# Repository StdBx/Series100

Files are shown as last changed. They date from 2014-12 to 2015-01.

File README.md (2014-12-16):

Series100
=========

StdBx is a set of tools and libraries intended to make it easy to create professional looking control and display panels for your electronics DIY projects.  Series100 is a design point for an enclosure that looks like this:  

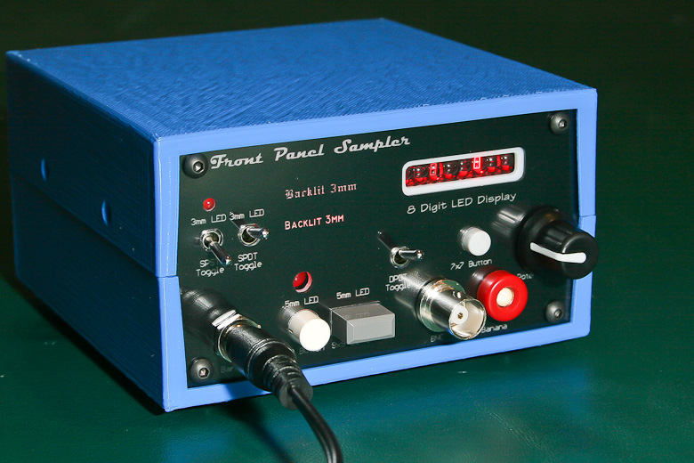
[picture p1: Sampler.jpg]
Series100 Sampler Enclosure shows a range of possible switches and displays
  
Series100 Sampler Enclosure 

The panels fit into an enclosure that has mounting for the circuit boards and end panels.  The enclosure design is provided in .stl format that can be printed on a 3d printer or ordered from a 3d print service company like [MakeXYZ](http://www.makexyz.com/) or [Shapeways](http://www.shapeways.com/).  

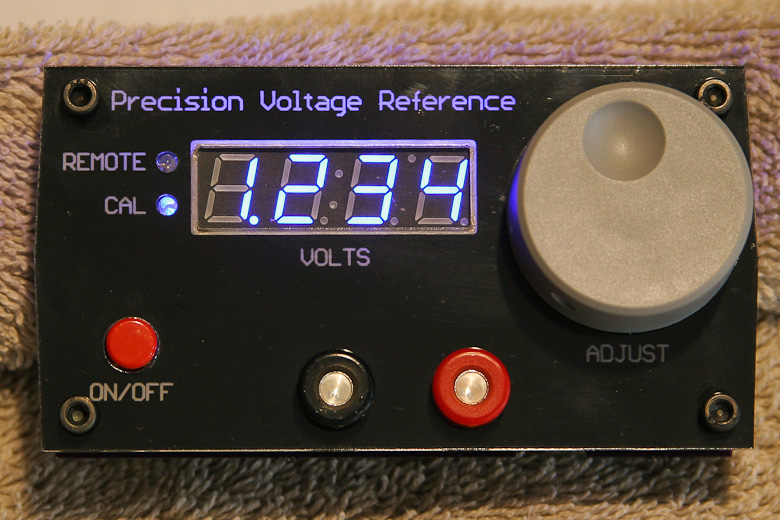
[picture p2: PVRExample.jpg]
Series100 Inside
  
Front Panel Example (early prototype)

Series100 adds a library and a CAM file to the EagleCAD PCB design software.  As you design your circuit board the front panel is designed along with it.  It is easy to use following these steps.  

  1. Design your circuit using Eagle's schematic capture tool.  For displays, buttons, switches, encoders, potentiometers and LEDs choose components from the Series100 library.  Include the Series100 board definition from the library.  
  2. Place the display and control components (along with the other components used in your design) using Eagle's PCB layout tool.  
  3. Add any text labels you would like to have on the panel.  
  4. Export the panel definition using the CAM file and scripts provided.  
  5. Order your panel from a laser cutting service like [Pololu](http://www.customlasercutting.com/) using the exported files.

That's it.  The board and the panel fits accurately and securely in the enclosure.  Together they allow your unique project to look like it just rolled off the manufacturing line.  

For a more detailed description and instructions start with the [!READ ME FIRST](https://github.com/StdBx/Series100/blob/master/Documentation/!READ%20ME%20FIRST.pdf) file in the Documentation folder.  You can also read more at the SparkFun forum [here](https://forum.sparkfun.com/viewtopic.php?f=5&t=39492).  

License: All design files are licensed under Creative Commons Universal.  You are welcome to modify the designs or even use them in commercial products.  We ask that you acknowledge that your design is based on StdBx and hope that if you create any additional components or enclosure designs that you contribute them back to the StdBx libraries.  

The StdBx name is copyright (c) 2014 C.Schnarel, all rights reserved. (i.e. don't create stuff and call it StdBx if it isn't part of one of the StdBx repositories.)

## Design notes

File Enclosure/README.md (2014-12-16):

Series100 Enclosure
===================

The StdBx Series100 is a box for your electronic projects.  The size is 4.25"W x 2.375"H x 4.1875"D.

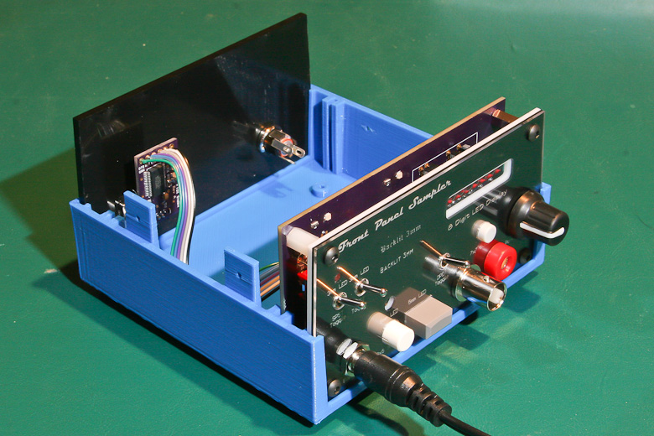
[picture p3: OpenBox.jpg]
Series100 Inside
  
Series100 Inside 

As you can see in this picture the StdBx system is based on a mechanical architecture similar to that used by any number of other instruments. There is an acrylic faceplate with a PCB behind it. The PCB is small enough to be designed with the free version of Eagle CAD, but can have a little over 8.5 square inches of circuitry. If that's not enough, the enclosure supports more PCBs on the back panel and floor of the enclosure for a total of 26.5 square inches of circuitry. You can add even more PCBs if you get creative by stacking. You don't have to use that much PCB but it's available if you need it.  

The floor of the enclosure is also sized to fit a 4xAA cell battery holder for more portable projects. You can use standard panel mount connectors on the back panel instead of a PCB. The two shown are a barrel jack for power and a rugged USB-mini-B connector with FTDI serial converter.

The enclosure is assembled from two identical pieces.  The two pieces are fastened with two screws on each side.  Together they capture the front and back panels and their associated PCBs.  There are mounting bosses for the third PCB on the floor of the enclosure.

The file Series100halfcaseRev3.1.stl in this folder is the mechanical definition for the enclosure.  You can print the file on your 3D printer or order it from 3D print companies like [MakeXYZ](http://www.makexyz.com/) or [Shapeways](http://www.shapeways.com/).  We have used both sources and the resulting prints work great.

The pieces we have tested from MakeXYZ were printed from PLA at a 200 micron layer height.  The pieces from Shapeways were printed from their "Strong & Flexible Plastic" material.  Both sources provide a range of print colors.

If you click on the stl file GitHub will provide an interactive 3D rendering.

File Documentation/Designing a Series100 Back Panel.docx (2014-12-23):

# Designing a Series100 Back Panel

The two ends of the Series100 enclosure are the same so strictly speaking you could put a “front” panel on both ends if you like, but often you don’t need the space or the cost of another circuit board. To fill this need for a simpler solution, the Series100 design point includes support for a back panel. Back panels are the same shape and size as front panels but they are made from a single piece of opaque acrylic and have no associated circuit board or PCB mounting holes.

Since the design is so simple you could just cut out a back panel piece by hand. You could drill it for connectors that have a round mounting hole, like a barrel jack. Then again, some connectors, like USB, have a more complex cutout shape, and the panel itself is a squashed hexagon, not rectangular. These additional complexities mean that, for me at least, getting a laser cut panel will result in a much better looking project than if I tried to fabricate the back panel by hand.

Use the steps below to create the back panel design files. Note that we’re still using Eagle even though we’re not designing a circuit board.

1. Using Eagle CAD create a new schematic file. Add the component “SERIES_100_BACKPANEL” (SB0029) from the “StdBxLibrary.lbr”. Place the component anywhere on your schematic.  NOTE: At this time the SERIES_100_BACKPANEL is in the “StdBxLibrary_BETA_.lbr” until it has been validated.
2. Click the “Generate/Switch to Board” button. You will get a dialog stating that your board file does not exist. Click “Yes” to create the board file from the schematic.
3. When the layout editor opens it will show the default board outline generated by Eagle. Delete the default board outline.
4. Click the “Layer Settings…” button and show layers 51, 244, and 246. Click “OK”.
5. Move the Series100 back panel so that the component origin is on the layout editor origin (the cross-hair). Once the board outline is moved you can click the “Zoom to Fit” button to make the board outline fill the edit window.
6. Click the “Switch to Schematic” button to go back to the schematic editor.
7. In the schematic editor add the rest of your back panel components. Components designed specifically for the back panel are noted in the component description. Most other components will not work since they mount to the PCB which is not there in this case.
8. Switch back to the board layout editor and place the components that you added. You don’t need to connect the components on the schematic or route them since there is no circuit board. Also, the components have an outline on the tDoc layer showing the size of the component. Don’t place components too close to the edges of the panel.
9. You can get a preview of your back panel layout by clicking on the “Layer Settings…” button and making layers 244 and 246 visible. Click “Apply”. This might give you a very cluttered view. To simplify the edit window and see the back panel more clearly, click the “None” button, then re-enable layers 244 and 246 and click “Apply”. Now you can see just the back panel items. When you are finished editing which layers to view, click the “Ok” button. Note that you cannot edit layers that are not visible.
10. Once you have your front panel laid out you can output the StdBx laser cutting and engraving files. NOTE: Just like outputting GERBER files, you do this only when your design is ready to be fabricated.  To output the StdBx files, click the “Run ULP” button in the layout editor. In the dialog that pops up choose “cam2dxf.ulp” and click “Open”. Next an open-file dialog will appear. In this dialog choose “StdBxSeries100.cam” and again click “Open”. Next another dialog will open with a Help tab. Click “OK” at this dialog. You will see some activity in the layout editor window, but pretty quickly that stops. If you then look in the same folder as the schematic and board layout you will see two new files, myBackPanelDesign_Bottom and myBackPanelDesign_Top. For the back panel you will only use the myBackPanelDesign_Top.
11. That’s it. You have designed your back panel.
12. See “Ordering the Back Panel” to get your back panel fabricated.

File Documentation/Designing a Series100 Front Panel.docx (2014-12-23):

# Designing a Series100 Front Panel

This is a first and pretty rough draft of the instructions for using Eagle to create a StdBx front panel layout. Provide feedback by opening issues in GitHub or send email to stdbxmdrtr@gmail.com.

1. Using Eagle CAD create a new schematic file. Add the component “SERIES_100” (SB0002) from the “StdBxLibrary.lbr”. Place the component anywhere on your schematic.
2. Click the “Generate/Switch to Board” button. You will get a dialog stating that your board file does not exist. Click “Yes” to create the board file from the schematic.
3. When the layout editor opens it will show two board outlines. The one on the left is the StdBx Series100 board definition. You can recognize it because it has mounting holes in the corners. The one on the right is the default board outline generated by Eagle. The default outline has no mounting holes. Delete the default board outline (the one on the right).
4. Move the Series100 board outline so that the bottom left corner is on the layout editor origin (the cross-hair). Once the board outline is moved you can click the “Zoom to Fit” button to make the board outline fill the edit window.
5. Click the “Switch to Schematic” button to go back to the schematic editor.
6. Draw the rest of your schematic. For LEDs, displays, switches, buttons, potentiometers, rotary encoders or any other component that “shows” through the front panel, choose only components from the “StdBxLibrary.lbr”. Components that do not show on the front panel can be chosen from any library. Note that even components that don’t show that are placed on the Top of the PCB can be no taller than 11 mm.
7. Continue your normal schematic edit and board layout process until your design is complete.
8. You can get a preview of your front panel layout by clicking on the “Layer Settings…” button and making layers 244, 245 and 246 visible. Click “Apply”. This might give you a very cluttered view. To simplify the edit window and see the front panel more clearly, click the “None” button, then re-enable layers 244, 245 and 246 and click “Apply”. Now you can see just the front panel items. When you are finished editing which layers to view, click the “Ok” button. Note that you cannot edit layers that are not visible.
9. If you wish to add labels or legends to your front panel you can do so by clicking the “Text” tool button. When the dialog opens type in your text and click “Ok”. Before you place your text, set the layer to “245 FP-Reveal” and the Ratio to “0%”. You can set the size to anything you like however smaller text does not engrave as well as larger text. I have found that .05” is about the smallest I’m comfortable with. Once you have set the layer, size and ratio you can place the text wherever you would like. Keep in mind that the enclosure covers the outermost 1/16” of the front panel and knobs cover more than just the diameter of the shaft.
10. Once you have your front panel laid out and text placed you can output the StdBx laser cutting and engraving files. NOTE: Just like outputting GERBER files, you do this only when your design is ready to be fabricated. If you output your StdBx files and then make more edits to the PCB then the front panel might not match the PCB anymore.  To output the StdBx files, click the “Run ULP” button in the layout editor. In the dialog that pops up choose “cam2dxf.ulp” and click “Open”. Next an open-file dialog will appear. In this dialog choose “StdBxSeries100.cam” and again click “Open”. Next another dialog will open with a Help tab. Click “OK” at this dialog. You will see some activity in the layout editor window, but pretty quickly that stops. If you then look in the same folder as the schematic and board layout you will see two new files, myDesign_Bottom and myDesign_Top.
11. That’s it. You have designed your front panel. If you find you do have to edit your PCB layout, just remember to go back and repeat step 10. Also, the text placed on layer 245 does NOT move automatically when you move components so remember to move the text when you move the component it goes with.
12. See “Ordering the Front Panel” to get your front panel fabricated.

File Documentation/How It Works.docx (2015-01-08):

# How it works

Although each project is different, all StdBx designs use a common architectural structure to fit into the enclosure. A cross section diagram of the structure shows how the parts work together.

The design starts with a PCB that has the user interface components (buttons, switches, displays, connectors, etc) mounted to it. In front of the PCB is the front panel that protects the PCB components and provides the surface for labels. There is a library of common components that the designer can choose from. Each component in the library was chosen so that it looks and works well with the structure. The PCB and the panel are separated by threaded spacers and are captured and held in place by channels in the enclosure.

The front panel is designed as a sandwich of three layers. I call these Epi, Reveal and Diffuser. The top Epi layer is always clear with cutouts for controls or connectors that protrude through the panel. The middle Reveal layer is opaque with cutouts for protrusions and labels. The bottom Diffuser layer is translucent. It has cutouts for protrusions and things like displays that should not be blurred.

Without backlight the Diffuser layer enhances the contrast of the cutouts in the Reveal layer. With backlight the labels or indicators cut in the Reveal layer light up. In terms of laser cut plastic there are actually just two pieces that are fastened together when mounted in the enclosure. The Reveal layer is bonded to clear acrylic (i.e. 2-ply acrylic). This is so that letter interiors don't fall away as part of the engraving process. When the Reveal layer is engraved away, it leaves the surface of the acrylic rough making it translucent rather than transparent so it can act as the Diffuser layer.

Here’s another cross section example.

<display section>

In this case a graphical display is mounted to the PCB. There is a cutout in the Reveal layer so that the backlit LCD shines through. There is also a cutout in the Diffuser layer so that the display is not blurred. Note that there is NOT a cutout in the clear Epi layer so the display is protected. Also, the Reveal and Diffuser layers are not exactly the same size making for a bezel around the display that dresses it up.

Here is another way to look at it. The lines in each of the Epi, Reveal and Diffuser layers define cutouts for that layer. Lines in Epi and Diffuser cut all the way through. Since Reveal and Diffuser are bonded together we cut through the Reveal layer using engraving. A side-effect or caveat is that since cutouts in the Diffuser layer cut all the way through, they are automatically cutouts in the Reveal layer. Watch out for this if you are designing your own components.

All the components in the StdBxLibrary have Epi, Reveal and Diffuser layers defined for the specifics of that component. The engraving and cutouts in these layers along with the PCB layout information and the mechanical characteristics have all been chosen so that they fit with the spacing between the PCB and the front panel as well as the thickness of the front panel.

When you place a component from the StdBxLibrary onto your PCB you are also placing that component’s Epi, Reveal and Diffuser definitions. Placing the “SERIES_100” (SB0002) component has the added function of defining both the PCB and the front panel outlines.

When you run the ULP with the StdBxCAM file, you cause Eagle CAD to output two files that the laser cutting service can translate into commands for the laser. One file is for the front panel Top piece. The other file is for the 2-ply front panel Bottom piece.

An alternative construction, that is more expensive but looks a little better, uses separate pieces of acrylic for the Reveal and Diffuser layers.

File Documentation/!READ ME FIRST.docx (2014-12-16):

# READ ME FIRST

This is a first and pretty rough draft. Provide feedback by opening issues in GitHub or send email to stdbxmdrtr@gmail.com.

The StdBx instruction files are all task based. That is, they are focused on the steps for getting one thing done. This keeps each set of instructions simpler and no more than a page or two in length.

This document describes things at more of an introductory or overview level. It provides a roadmap leading to the individual instruction files.

All of the instructions and StdBx files were created for and tested using Eagle CAD version 6.6.0 running on a Windows 7 computer. If your operating system or version of Eagle is different, you may have to adjust the instructions some. The instructions also assume that you are somewhat familiar with creating circuit boards using Eagle CAD. If you have little or no experience with Eagle, you might want to start by getting familiar with Eagle before adding StdBx. At a minimum you should already have Eagle installed and have learned to create schematic and board files. There are plenty of tutorials and YouTube videos that teach these Eagle basics.

The first thing to do with StdBx is to install it. The instructions for that are in the file “Installing StdBx Files into Eagle”.

Then to start your StdBx design, follow the instructions in the file “Designing a Series100 Front Panel”. If instead you are designing a back panel, follow the instructions in “Designing a Series100 Back Panel”.

To have your front panel laser cut from acrylic, follow the instructions in “Ordering the Front Panel”.

A key part of making StdBx work is getting the right components. For some help getting the parts for your circuit board, front panel, and the enclosure, follow the instructions in “Finding Parts for Your StdBx”.

That is really all you need for the basics. The following topics teach you how to do more customization. These tasks will make your front panel more unique, but with that you also take more risk that you might require more than one try to get things right. Plus you will have to use tools beyond Eagle CAD. Using these additional steps may also increase the cost of the front panel. Front panels are not too expensive, around $15. But if you have to try three times to get one that works that’s around $45 and that is expensive. Like anything, practice will help you make fewer mistakes, but if you are concerned with spending or with having your front panel not work right, stick with the steps above. I can’t guarantee that sticking to the steps above will always create a perfect front panel on the first try but that is what StdBx is designed for and we’ll continue to work to get as close to that as we can.

[Optional and Dangerous] To add a part that is not in the StdBx library, follow the instructions in “Creating a New Series100 Component”.

[Optional and Dangerous] Eagle supports only its own fonts (proportional and vector) from within the program; to learn how to create a front panel with other fonts, follow the instructions in “Using Custom Fonts on Your Front Panel”.

The instruction files above tell you how to use StdBx. In the “How It Works” document I will give a little information on how StdBx creates front panel files from your Eagle design. You don’t need to know how StdBx works to use the basics, but having a deeper understanding might help you move to the “Optional and Dangerous” topics, or might just give you more confidence in StdBx overall.

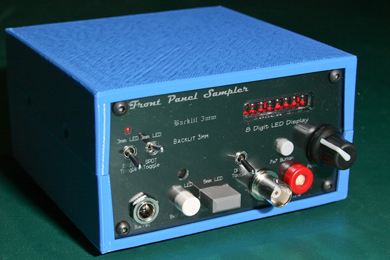
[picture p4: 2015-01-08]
SamplerHalfSize.jpg

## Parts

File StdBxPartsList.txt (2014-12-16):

Part No.,Name,Rev,Filetype,Description,Status
SB0001,"Enclosure, Series100halfcase",3.1,.stl,Enclosure component. Two pieces required (plus front and back panels) to form enclosure.,Beta
SB0002,"Panel, Series_100, Front with PCB",1.0,.lbr,"Eagle lbr component.  Defines front panel outline with mounting holes.  Defines standard PCB outline with mounting holes, keepouts and height restrictions.",Beta
SB0003,"Switch, Push Button, DPDT, 7mm Round Cap",1.0,.lbr,Push button for front panel with round cap.  Available in momentary and push-on/push-off.  Various cap colors.,Beta
SB0004,"Display, 7-Seg 4-Dig LED",1.0,.lbr,"LED 4-digit display, 10mm(0.39"") high, with bezel.  Available in various colors.",Beta
SB0005,"Display, 16x2 LCD ",1.0,.lbr,LCD display with bezel. Based on 16x2 LCD display from SparkFun library.  Parallel interface version.,Beta
SB0006,"Display, 7-Seg 8-Dig LED",1.0,.lbr,"LED 8-digit display with bezel.   Display height, 0.2"", appears larger due to bubble.  See SB0025 for module definition.",Beta
SB0007,"LED, 3mm, Clear",1.0,.lbr,Single 3 mm LED.  LED lens on front panel is clear. (cut out on reveal and diffused layers),Beta
SB0008,"LED, 3mm, Diffused",1.0,.lbr,Single 3 mm LED.  LED lens on front panel is diffused. (cut out on reveal layer only),Beta
SB0009,"LED, 5mm, Clear",1.0,.lbr,Single 5 mm LED.  LED lens on front panel is clear. (cut out on reveal and diffused layers),Beta
SB0010,"LED, 5mm, Diffused",1.0,.lbr,Single 5 mm LED.  LED lens on front panel is diffused. (cut out on reveal layer only),Beta
SB0011,"Switch, Encoder, Rotary",1.0,.lbr,Encoder with push-button.,Beta
SB0012,Potentiometer,1.0,.lbr,Potentiometer.  Various values.  Linear or log taper.,Beta
SB0013,"Switch, Toggle, SPST",1.0,.lbr,"Toggle switch, SPST (2 pin),  off/on.  Can be mounted with or without front nut.",Beta
SB0014,"Switch, Toggle, SPDT",1.0,.lbr,"Toggle switch, SPDT (3 pin).  Can be mounted with or without front nut.  Available in on-on, on-off-on, mom-off-mom, on-off-mom, on-mom.",Beta
SB0015,"Switch, Toggle, DPDT",1.0,.lbr,"Toggle switch, DPDT (6 pin).  Can be mounted with or without front nut.  Available in on-on, on-off-on.",Beta
SB0016,"Connector, BNC",1.0,.lbr,Mounts to front panel with nut (back side) AND soldered to circuit board.,Beta
SB0017,"Connector, Banana Plug Recepticle",1.0,.lbr,Accepts standard 5mm banana plug.  Available in various colors.  Mounts to front panel with nut (back side) AND soldered to circuit board.,Beta
SB0018,"Connector, Power, Barrel Jack 2.1x5.5",1.0,.lbr,Mounts to front panel with nut (front side) AND soldered to circuit board.,Beta
SB0019,"Switch, Push Button, DPDT, 6x12mm Rect Cap",1.0,.lbr,Push button for front panel with rectangular cap.  Available in momentary and push-on/push-off.  Various cap colors.,Beta
SB0020,"Switch, Push Button, DPDT, 6mm Round Cap",1.0,.lbr,Push button for front panel with round cap.  Available in momentary and push-on/push-off.  Various cap colors. Caps hard to find.,Beta
SB0021,"Connector, USB mini-B",1.0,.lbr,BACK PANEL ONLY - DOES NOT MOUNT TO PCB!  Defines cutouts for mounting connector to back panel but wrong height for std PCB mount.  See SB0023 or SB0024 for daughter-card to ribbon cable to PCB.,Beta
SB0022,"Connector, Power, BACK PANEL ONLY, Barrel Jack 2.1x5.5",1.0,.lbr,BACK PANEL ONLY - DOES NOT MOUNT TO PCB!  Defines cutouts for mounting connector to back panel but wrong height for std PCB mount.  Use wires to connect to PCB.,Beta
SB0023,"Module, USB",1.0,Eagle,Bridges connector pins to ribbon cable.  Use for applications that take USB directly.  See SB0024 for FTDI.,Beta
SB0024,"Module, FTDI, USB-to-serial",1.0,Eagle,Puts USB to serial onto USB connector then ribbon cable to main PCB.  Std 6-pin FTDI interface.,Beta
SB0025,"Module, Display, 7-Seg 8-Dig LED",1.0,Eagle,PCB design files for 8 digit LED display based on HP Bubble 4-digit parts.  Serial input for segments reduces pins.,Beta
SB0026,"PCB, Series100, Base",1.0,Eagle,PCB design files for board that mounts to bottom of enclosure.,Beta
SB0027,"PCB, Series100, Proto",1.0,Eagle,PCB design files for prototyping board that fits Series100 case and front panel.  Overlay components in Eagle to generate Front Panel files.,Beta
SB0028,"PCB, Series100, Proto with UNO",1.0,Eagle,PCB design files for prototyping board that fits Series100 case and front panel with mounting for Arduino UNO board.  Overlay components in Eagle to generate Front Panel files.,Beta
SB0029,"Panel, Series_100, Back",1.0,.lbr,"Eagle lbr component.  Defines panel outline without mounting holes.  No PCB definition.  For mounting ""panel mount"" components like SB0021 and SB0022.",Beta
SB0030,"Switch, Push Button, DPDT, 5x5mm Rect Cap",1.0,.lbr,Push button for front panel with rectangulare cap.  Available in momentary and push-on/push-off.  Various cap colors.,Beta
SB0031,"Switch, Encoder, Rotary",1.0,.lbr,Encoder with push-button.,Beta

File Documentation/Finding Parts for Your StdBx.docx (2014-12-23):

# Finding Parts for Your StdBx

The instructions here are focused on the task of choosing StdBx components and acquiring matching parts. For a more “Why?” and “How is it implemented?” description see the document “StdBx PartsBD”.

As you go about designing the user interface for your project you will probably think in terms of building blocks like buttons or different kinds of displays. You can find a selection of these types of components in the StdBxLibrary.lbr.

NOTE: START UP ISSUE: At this time most components are in the “StdBxLibrary_BETA_.lbr” until they have been validated.

Each component in the library has a description that tells the details about the component and what variations are available. The description also includes a StdBx part number. Hopefully there is enough information in the description to allow you to choose the component that you want, but eventually you will want to get more detail or more likely you will need to purchase parts for your project.

To research a part in more depth, or to purchase it, note the StdBx part number from the library. If you have Excel or can open Excel files in your spreadsheet program, open the “PartsDB.xlsx” file and switch to the “Vendor Parts” tab. If you do not have a spreadsheet, the same information is also available in the text file, “VendorPartNumsDB.txt”.

Once you have the file open, search for the StdBx part number that you noted earlier. You will find at least one and potentially many file entries with that part number. You will need to choose the one that best fits your needs. Once you have the entry you want, use the vendor and part number for that entry.

Let’s use an example to illustrate the process. You have decided to use a single-pole, double-throw toggle switch (SB0014) in your project. The switch is used to control an animated LED display and has three positions. In one position the LED animation is off. In another position the LED animation runs. In the third position the LED animation can be advanced one step at a time. The switch we are looking for is an on-off-mom version.

If you look in the parts database you will find that there are twelve entries with the SB0014 part number. Any of these parts will mechanically fit onto the PCB and will work properly with the front panel design. Reading through the descriptions you can see that only one of the entries has the desired on-off-mom function that we want. That switch is made by C&K and is their part number 107SHCQE. You can also see that this switch is stocked by Mouser (http://www.mouser.com/) part number 611-T105SHCQE and can be purchased in single units on their website.

There is a reasonable selection of components in the StdBxLibrary to design your front panel and more will be added over time. It might be valuable to read through the list of available components to have that knowledge as you plan out your design. If there is something that you need that is not available, you can follow the instructions in the file “Creating a New Series100 Component” to create it for yourself. Or if it is a component that you feel many would be interested in using you can open an enhancement issue on GitHub (https://github.com/StdBx/Series100). Or create it yourself and submit your component via a GitHub pull request.

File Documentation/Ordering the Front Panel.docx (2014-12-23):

# Ordering the Front Panel

This is a first and pretty rough draft. Provide feedback by opening issues in GitHub or send email to stdbxmdrtr@gmail.com. These instructions were developed on and for Eagle 6.6.0 running on a Windows 7 PC. If you have a different version of Eagle or a different OS you may need to adapt the instructions to your system.

Once you have finished your design in Eagle and have output the front panel files you are ready to order the laser cut acrylic pieces. The instructions here will walk you through ordering laser cut parts from Pololu (http://www.customlasercutting.com/); however other laser cutting and engraving services should be able to accomplish the same result. If you use another service you will have to adapt these instructions to the order process of the service you use.

Before you can place an order for your front panel parts you need to request a quote (http://www.customlasercutting.com/quote/overview). This is where you upload your design files, tell the service what material you want the parts cut from and explain any other special instructions needed. To make one front panel you are going to order two parts. From Pololu’s perspective you are ordering two laser cutting designs.

On the “New quote (http://www.pololu.com/laserquote/new)” page click on the “Browse…” button. In the dialog that opens navigate to your Eagle Projects folder and select the mydesign_Top file. Click Open to upload the file.

Paste the following text into the “Quantity:” window.

1 copy of layout defined in the file

Paste the following text into the “Special Instructions:” window.

StdBx Series100 Front Panel Design (top)
All lines in this file are cuts all the way through.
Material: 1/16" Transparent Clear Acrylic
Scale: mm, component should be 4.1" by 2.2"

Below the Special Instructions window will be a list of all the different materials available. Find the line that looks like the picture below and click the “Use this material” button at the right of the line.

When you click the “Use this material” button the Pololu page updates with a summary of your request. Check that the summary matches what you intend to order. Below the summary is the “Add another design” button. Click it.

Again the page will update. Click the “Browse…” next to My Files: and navigate to your Eagle Projects folder and select the mydesign_Bottom file. Click Open to upload the file.

Paste the following text into the “Quantity:” window.

1 copy of layout defined in the file

Paste the following text into the “Special Instructions:” text box.

StdBx Series100 Front Panel Design (bottom)
Material: IPI Laserables Reverse LZR901G 1/16"
2-ply, engraved on opaque side
Scale: inches, component should be 4.1" by 2.2"
Layer 244 (yellow): cut all the way through
layer 245 (magenta): Engraved reverse. Text should read correct when viewed from NOT engraved side. Text stroke width should be 0.015 inches. All closed shapes (layer 245 ONLY) should be filled.
Engrave Depth: .003" (opaque layer to be engraved off leaving engraved area translucent)

Scroll all the way to the bottom of the web page. There you will find another text box and button that looks like this:

Paste the following text into the box and click the “Use this material” button to the right of the box.

IPI Laserables Reverse LZR901G 1/16"

NOTE: START UP ISSUE: Currently Pololu does not stock or even special order this 2-ply material. You can order the material from Johnson Plastics (http://www.johnsonplastics.com/) and have them ship it to Pololu. Hopefully we will be able to get Pololu to stock this material soon.

Again the page will update. The new page will have a summary of both pieces for your design. If you are ordering a back panel at the same time, click the “Add another design” button. If not, check the box next to “I have read and understand the laser cutting capabilities and limitations…”. Then click the “I am a new customer” radio button and fill out the form to set up and account. Finally, click the “Submit quote request” button.

In a couple of days you should get a quote email that tells you how much your order will cost and provide a link to the quote. Click on the link. Once your quote page opens click on the links for the preview files. These are PDF files that Pololu has interpreted from the design files uploaded. Check these PDFs over carefully. The blue lines are cuts all the way through the material. The black lines and areas are the places that will be engraved. Once you approve the quote Pololu will make the pieces just like the files. If it’s wrong on the file and you approve it, Pololu will not be responsible.

After you have approved the check files scroll to the bottom of the page and click to place your order. The price goes up the faster you want your parts.

That’s it. Your front panel will be shipped to you on the schedule you requested. Of course, you also need to order the parts that will go into your project. For some help ordering the StdBx parts, take a look at the instructions in the file “Finding Parts for Your StdBx”.

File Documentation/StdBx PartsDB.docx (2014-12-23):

# StdBx PartsDB

Just like the same mechanical package can be used for many different ICs, so too can the same Eagle library component be used for many different vendor parts. For example, the same library component can represent a red LED or a green one. What’s important to the library component is that the LEDs share the same mechanical shape, pad layout and panel cutouts or engravings. Similarly the same library component for a push button can represent a momentary contact button or a push-on/push-off button. The mapping from library component to vendor parts can be one to many.

The reverse is also true. The same vendor part for an LED can be used for the library component with panel cutouts to make it show through clear or with another library component that is an engraved spot to have the LED be diffused. Another example would be two different library components that represent the same switch, one with a round cap, the other with a rectangular cap. So the mapping from vendor part to library components can also be one to many.

To facilitate this many-to-many mapping StdBx uses a parts database rather than just the Eagle component library. Each library component carries the definition of the front panel layers as well as the normal schematic and board layout representations. Also, it is a requirement that the StdBx library components be readily available. Therefore there may be multiple vendors and/or multiple manufacturers for each component. Since both retailers and manufacturers add and drop components all the time, the information needs to be maintained dynamically but it would cause unnecessary churn to the Eagle library to have to update it every time a new vendor is found or a manufacturer introduces a new color.

The database need not be complex or require special tools. The master information will be maintained as a Microsoft Excel (.xlsx) file, but the data will also be saved as CSV text so that it can be imported into any spreadsheet or database, or just read as text.

Therefore: Each component in the StdBxLibrary.lbr will be assigned a part number. The format for the number is “SBxxxx” where xxxx is a four digit number. So that we can also track enclosure variants or other StdBx pieces, these too will receive a part number. A master list of StdBx part numbers will be maintained. Each entry will record the part number, name, revision, definition file type, description, and status. A second list will be maintained that contains a list of vendor parts that can be used with each StdBx library component. Each entry will record the vendor, vendor part number, StdBx part number, manufacturer, manufacturer part number, name and notes. No component shall be added to the library unless the part for that component is readily available.

The purpose of the master list of StdBx part numbers is to facilitate allocation of new part numbers and manage development and status of all StdBx components.

To find a part for your project determine the kind of part you need and choose that component from the component library. Note the StdBx part number. Then look up that StdBx part number in the vendor part number list. You may find multiple vendors or vendor part numbers that match. You should always find at least one.

If you should ever want to submit a new library component for inclusion in StdBx, please also submit one or preferably multiple vendors’ part numbers that fit the component.

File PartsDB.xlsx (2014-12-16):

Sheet: StdBx Parts
Part No. | Name | Rev | Filetype | Description | Status
SB0001 | Enclosure, Series100halfcase | 3.1 | .stl | Enclosure component. Two pieces required (plus front and back panels) to form enclosure. | Beta
SB0002 | Panel, Series_100, Front with PCB | 1.0 | .lbr | Eagle lbr component. Defines front panel outline with mounting holes. Defines standard PCB outline with mounting holes, keepouts and height restrictions. | Beta
SB0003 | Switch, Push Button, DPDT, 7mm Round Cap | 1.0 | .lbr | Push button for front panel with round cap. Available in momentary and push-on/push-off. Various cap colors. | Beta
SB0004 | Display, 7-Seg 4-Dig LED | 1.0 | .lbr | LED 4-digit display, 10mm(0.39") high, with bezel. Available in various colors. | Beta
SB0005 | Display, 16x2 LCD | 1.0 | .lbr | LCD display with bezel. Based on 16x2 LCD display from SparkFun library. Parallel interface version. | Beta
SB0006 | Display, 7-Seg 8-Dig LED | 1.0 | .lbr | LED 8-digit display with bezel. Display height, 0.2", appears larger due to bubble. See SB0025 for module definition. | Beta
SB0007 | LED, 3mm, Clear | 1.0 | .lbr | Single 3 mm LED. LED lens on front panel is clear. (cut out on reveal and diffused layers) | Beta
SB0008 | LED, 3mm, Diffused | 1.0 | .lbr | Single 3 mm LED. LED lens on front panel is diffused. (cut out on reveal layer only) | Beta
SB0009 | LED, 5mm, Clear | 1.0 | .lbr | Single 5 mm LED. LED lens on front panel is clear. (cut out on reveal and diffused layers) | Beta
SB0010 | LED, 5mm, Diffused | 1.0 | .lbr | Single 5 mm LED. LED lens on front panel is diffused. (cut out on reveal layer only) | Beta
SB0011 | Switch, Encoder, Rotary | 1.0 | .lbr | Encoder with push-button. | Beta
SB0012 | Potentiometer | 1.0 | .lbr | Potentiometer. Various values. Linear or log taper. | Beta
SB0013 | Switch, Toggle, SPST | 1.0 | .lbr | Toggle switch, SPST (2 pin), off/on. Can be mounted with or without front nut. | Beta
SB0014 | Switch, Toggle, SPDT | 1.0 | .lbr | Toggle switch, SPDT (3 pin). Can be mounted with or without front nut. Available in on-on, on-off-on, mom-off-mom, on-off-mom, on-mom. | Beta
SB0015 | Switch, Toggle, DPDT | 1.0 | .lbr | Toggle switch, DPDT (6 pin). Can be mounted with or without front nut. Available in on-on, on-off-on. | Beta
SB0016 | Connector, BNC | 1.0 | .lbr | Mounts to front panel with nut (back side) AND soldered to circuit board. | Beta
SB0017 | Connector, Banana Plug Recepticle | 1.0 | .lbr | Accepts standard 5mm banana plug. Available in various colors. Mounts to front panel with nut (back side) AND soldered to circuit board. | Beta
SB0018 | Connector, Power, Barrel Jack 2.1x5.5 | 1.0 | .lbr | Mounts to front panel with nut (front side) AND soldered to circuit board. | Beta
SB0019 | Switch, Push Button, DPDT, 6x12mm Rect Cap | 1.0 | .lbr | Push button for front panel with rectangular cap. Available in momentary and push-on/push-off. Various cap colors. | Beta
SB0020 | Switch, Push Button, DPDT, 6mm Round Cap | 1.0 | .lbr | Push button for front panel with round cap. Available in momentary and push-on/push-off. Various cap colors. Caps hard to find. | Beta
SB0021 | Connector, USB mini-B | 1.0 | .lbr | BACK PANEL ONLY - DOES NOT MOUNT TO PCB! Defines cutouts for mounting connector to back panel but wrong height for std PCB mount. See SB0023 or SB0024 for daughter-card to ribbon cable to PCB. | Beta
SB0022 | Connector, Power, BACK PANEL ONLY, Barrel Jack 2.1x5.5 | 1.0 | .lbr | BACK PANEL ONLY - DOES NOT MOUNT TO PCB! Defines cutouts for mounting connector to back panel but wrong height for std PCB mount. Use wires to connect to PCB. | Beta
SB0023 | Module, USB | 1.0 | Eagle | Bridges connector pins to ribbon cable. Use for applications that take USB directly. See SB0024 for FTDI. | Beta
SB0024 | Module, FTDI, USB-to-serial | 1.0 | Eagle | Puts USB to serial onto USB connector then ribbon cable to main PCB. Std 6-pin FTDI interface. | Beta
SB0025 | Module, Display, 7-Seg 8-Dig LED | 1.0 | Eagle | PCB design files for 8 digit LED display based on HP Bubble 4-digit parts. Serial input for segments reduces pins. | Beta
SB0026 | PCB, Series100, Base | 1.0 | Eagle | PCB design files for board that mounts to bottom of enclosure. | Beta
SB0027 | PCB, Series100, Proto | 1.0 | Eagle | PCB design files for prototyping board that fits Series100 case and front panel. Overlay components in Eagle to generate Front Panel files. | Beta
SB0028 | PCB, Series100, Proto with UNO | 1.0 | Eagle | PCB design files for prototyping board that fits Series100 case and front panel with mounting for Arduino UNO board. Overlay components in Eagle to generate Front Panel files. | Beta
SB0029 | Panel, Series_100, Back | 1.0 | .lbr | Eagle lbr component. Defines panel outline without mounting holes. No PCB definition. For mounting "panel mount" components like SB0021 and SB0022. | Beta
SB0030 | Switch, Push Button, DPDT, 5x5mm Rect Cap | 1.0 | .lbr | Push button for front panel with rectangulare cap. Available in momentary and push-on/push-off. Various cap colors. | Beta
SB0031 | Switch, Encoder, Rotary | 1.0 | .lbr | Encoder with push-button. | Beta

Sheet: Vendor Parts
Vendor # | Vendor | StdBx # | Status | Manufacturer | Mfr # | Name | Notes
611-PVB6THTOA300NS | Mouser | SB0003 |  | C&K | PVA6THT OA 300NS LFS | Switch, Push Button, DPDT, 7.4mm Round Cap, Momentary
611-PVB6THTEE300NS | Mouser | SB0003 |  | C&K | PVA6THT EE 300NS LFS | Switch, Push Button, DPDT, 7.4mm Round Cap, Push-on / Push-Off
401-1149-ND | Digi-Key | SB0003 |  | C&K | PV GY | Cap, Round 7.4 mm, Gray
401-1150-ND | Digi-Key | SB0003 |  | C&K | PV RD | Cap, Round 7.4 mm, Red
401-1148-ND | Digi-Key | SB0003 |  | C&K | PV BK | Cap, Round 7.4 mm, Black
401-1151-ND | Digi-Key | SB0003 |  | C&K | PV WH | Cap, Round 7.4 mm, White
COM-09483 | SparkFun | SB0004 |  | Young Sun | YSD-439AR6B-35 | Red, 7-Segment 4-Digit, 10mm (0.39") high, common anode, with colon & apostraphy
COM-10931 | SparkFun | SB0004 |  | ??? | ATA3492BW_2 | White, 7-Segment 4-Digit, 10mm (0.39") high, common anode, with colon & apostraphy
COM-09480 | SparkFun | SB0004 |  | Young Sun | YSD-439AY2B-35 | Yellow, 7-Segment 4-Digit, 10mm (0.39") high, common anode, with colon & apostraphy
COM-09482 | SparkFun | SB0004 |  | Young Sun | YSD-439AK2B-35 | Kelly Green, 7-Segment 4-Digit, 10mm (0.39") high, common anode, with colon & apostraphy
COM-09485 | SparkFun | SB0004 |  | Young Sun | YSD-439AB4B-35 | Blue, 7-Segment 4-Digit, 10mm (0.39") high, common anode, with colon & apostraphy
LCD-00709 | SparkFun | SB0005 |  | Xiamen Ocular | GDM1602K 5V | White on Black, 16x2 parallel input LCD
LCD-09052 | SparkFun | SB0005 |  | Xiamen Amotec Display Co Ltd | ADM1602K-NSW-FBS/3.3V | White on Black, 16x2 parallel input LCD
LCD-00255 | SparkFun | SB0005 |  | Xiamen Ocular | GDM1602K 5V | Black on Green, 16x2 parallel input LCD
LCD-09053 | SparkFun | SB0005 |  | Xiamen Amotec Display Co Ltd | ADM1602K-FSY-YBS/3.3V | Black on Green, 16x2 parallel input LCD
LCD-00790 | SparkFun | SB0005 |  | Xiamen Ocular | GDM1602K 5V | Yellow on Blue, 16x2 parallel input LCD
754-1604-ND | Digi-Key | SB0007 |  | Kingbright | WP710A10SRC/E | Red LED, 3mm, just one example of hundreds of compatible parts
754-1596-ND | Digi-Key | SB0007 |  | Kingbright | WP710A10QBC/D | Blue LED, 3mm, just one example of hundreds of compatible parts
754-1604-ND | Digi-Key | SB0008 |  | Kingbright | WP710A10SRC/E | Red LED, 3mm, just one example of hundreds of compatible parts
754-1596-ND | Digi-Key | SB0008 |  | Kingbright | WP710A10QBC/D | Blue LED, 3mm, just one example of hundreds of compatible parts
754-1274-ND | Digi-Key | SB0009 |  | Kingbright | WP7113SRC/DU | Red LED, 5mm, just one example of hundreds of compatible parts
754-1489-ND | Digi-Key | SB0009 |  | Kingbright | WP7113QBC/D | Blue LED, 5mm, just one example of hundreds of compatible parts
754-1274-ND | Digi-Key | SB0010 |  | Kingbright | WP7113SRC/DU | Red LED, 5mm, just one example of hundreds of compatible parts
754-1489-ND | Digi-Key | SB0010 |  | Kingbright | WP7113QBC/D | Blue LED, 5mm, just one example of hundreds of compatible parts
PEC12R-4225F-S0024-ND | Digi-Key | SB0011 |  | Bourns, Inc. | PEC12R-4225F-S0024 | ROTARY ENCODER, 24 counts per revolution, with switch, 6mm D-shaft | Needs shaft defn and knob ref
652-PEC12R-4225F-S24 | Mouser | SB0011 |  | Bourns, Inc. | PEC12R-4225F-S0024 | ROTARY ENCODER, 24 counts per revolution, with switch, 6mm D-shaft | Needs shaft defn and knob ref
987-1187-ND | Digi-Key | SB0011 |  | TT Electronics | EN11-HSB1AQ20 | ROTARY ENCODER, 20 counts per revolution, with switch, 6mm D-shaft | Needs shaft defn and knob ref
858-EN11-HSB1AQ20 | Mouser | SB0011 |  | TT Electronics | EN11-HSB1AQ20 | ROTARY ENCODER, 20 counts per revolution, with switch, 6mm D-shaft | Needs shaft defn and knob ref
PTV09A-4025F-Bxxx-ND | Digi-Key | SB0012 |  | Bourns, Inc. | PTV09A-4025F | Potentiometer, Rear Mount Bushingless, flat shaft | xxx = value. e.g. 103 = 10k, 202 = 2k, etc.
652-PTV09A-4025FBxxx | Mouser | SB0012 |  | Bourns, Inc. | PTV09A-4025F | Potentiometer, Rear Mount Bushingless, flat shaft | xxx = value. e.g. 103 = 10k, 202 = 2k, etc.
CKN10151-ND | Digi-Key | SB0013 |  | C&K | T102SHCQE | SWITCH, TOGGLE, SPST, 120V, 3A, PCB pins, off-on
611-T102SHCQE | Mouser | SB0013 |  | C&K | T102SHCQE | SWITCH, TOGGLE, SPST, 120V, 3A, PCB pins, off-on
612-200MSP6T1B1M2RE | Mouser | SB0013 |  | E-switch | 200MSP6T1B1M2RE | SWITCH, TOGGLE, SPST, 120V, 3A, PCB pins, off-on
CKN1091-ND | Digi-Key | SB0014 |  | C&K | T101SHCQE | SWITCH, TOGGLE, SPDT, 120V, 2A, PCB pins, on-on
611-T101-001 | Mouser | SB0014 |  | C&K | T101SHCQE | SWITCH, TOGGLE, SPDT, 120V, 2A, PCB pins, on-on
EG2447-ND | Digi-Key | SB0014 |  | E-switch | 200MSP1T1B1M2QEH | SWITCH, TOGGLE, SPDT, 120V, 2A, PCB pins, on-on
612-200-A1121 | Mouser | SB0014 |  | E-switch | 200MSP1T1B1M2QEH | SWITCH, TOGGLE, SPDT, 120V, 2A, PCB pins, on-on
CKN1092-ND | Digi-Key | SB0014 |  | C&K | T103SHCQE | SWITCH, TOGGLE, SPDT, 120V, 2A, PCB pins, on-off-on
611-T103-001 | Mouser | SB0014 |  | C&K | T103SHCQE | SWITCH, TOGGLE, SPDT, 120V, 2A, PCB pins, on-off-on
EG2451-ND | Digi-Key | SB0014 |  | E-switch | 200MSP3T1B1M2QEH | SWITCH, TOGGLE, SPDT, 120V, 2A, PCB pins, on-off-on
612-200-C1121 | Mouser | SB0014 |  | E-switch | 200MSP3T1B1M2QEH | SWITCH, TOGGLE, SPDT, 120V, 2A, PCB pins, on-off-on
611-T105SHCQE | Mouser | SB0014 |  | C&K | T105SHCQE | SWITCH, TOGGLE, SPDT, 120V, 2A, PCB pins, mom-off-mom
612-200MSP4T1B1M2QE | Mouser | SB0014 |  | E-switch | 200MSP4T1B1M2QEH | SWITCH, TOGGLE, SPDT, 120V, 2A, PCB pins, mom-off-mom
611-T105SHCQE | Mouser | SB0014 |  | C&K | 107SHCQE | SWITCH, TOGGLE, SPDT, 120V, 2A, PCB pins, on-off-mom
200MSP2T1B1M2RE-ND | Digi-Key | SB0014 |  | E-switch | 200MSP2T1B1M2RE | SWITCH, TOGGLE, SPDT, 120V, 2A, PCB pins, on-mom
612-200MSP2T1B1M2QE | Mouser | SB0014 |  | E-switch | 200MSP2T1B1M2RE | SWITCH, TOGGLE, SPDT, 120V, 2A, PCB pins, on-mom
CKN1182-ND | Digi-Key | SB0015 |  | C&K | T201SHCQE | SWITCH, TOGGLE, DPDT, 120V, 3A, PCB pins, on-on
T203SHCQE-ND | Digi-Key | SB0015 |  | C&K | T203SHCQE | SWITCH, TOGGLE, DPDT, 120V, 3A, PCB pins, on-off-on
611-T201-001 | Mouser | SB0015 |  | C&K | T201SHCQE | SWITCH, TOGGLE, DPDT, 120V, 3A, PCB pins, on-on
EG2456-ND | Digi-Key | SB0015 |  | E-switch | 200MDP1T1B1M2QE | SWITCH, TOGGLE, DPDT, 120V, 3A, PCB pins, on-on
612-200MDP3T1B1M2QE | Mouser | SB0015 |  | E-switch | 200MDP3T1B1M2QE | SWITCH, TOGGLE, DPDT, 120V, 3A, PCB pins, on-off-on
611-T201-001 | Mouser | SB0015 |  | E-switch | 200MDP1T1B1M2QE | SWITCH, TOGGLE, DPDT, 120V, 3A, PCB pins, on-on
A97548-ND | Digi-Key | SB0016 |  | TE Connectivity | 5-1634523-1 | BNC Connector, 50 Ohm, panel mount
J10124-ND | Digi-Key | SB0017 |  | Emerson Network Power Connectivity Solutions | 108-2302-621 | Banana Plug Recepticle, Red
J10142-ND | Digi-Key | SB0017 |  | Emerson Network Power Connectivity Solutions | 108-2303-621 | Banana Plug Recepticle, Black
CP-064A-ND | Digi-Key | SB0018 |  | CUI Inc | PJ-064A | Barrel Jack, 2.1x5.5mm
 | Digi-Key | SB0019 |  | C&K | PVA6THT OA 300NS LFS | Switch, Push Button, DPDT, 6x12mm Rect Cap, Momentary
 | Digi-Key | SB0019 |  | C&K | PVA6THT EE 300NS LFS | Switch, Push Button, DPDT, 6x12mm Rect Cap, Push-on / Push-Off
611-PVB6THTOA300NS | Mouser | SB0019 |  | C&K | PVA6THT OA 300NS LFS | Switch, Push Button, DPDT, 6x12mm Rect Cap, Momentary
611-PVB6THTEE300NS | Mouser | SB0019 |  | C&K | PVA6THT EE 300NS LFS | Switch, Push Button, DPDT, 6x12mm Rect Cap, Push-on / Push-Off
401-1153-ND | Digi-Key | SB0019 |  | C&K | PE GY | Cap, Rectangular 12x6 mm, Gray
401-1154-ND | Digi-Key | SB0019 |  | C&K | PE RD | Cap, Rectangular 12x6 mm, Red
401-1152-ND | Digi-Key | SB0019 |  | C&K | PE BK | Cap, Rectangular 12x6 mm, Black
401-1155-ND | Digi-Key | SB0019 |  | C&K | PE WH | Cap, Rectangular 12x6 mm, White
612-TL2230-OA | Mouser | SB0020 |  | E-Switch | TL2230OAF140 | Switch, Push Button, DPDT, 6mm Round Cap, Momentary
612-TL2230EEF100 | Mouser | SB0020 |  | E-Switch | TL2230EEF100 | Switch, Push Button, DPDT, 6mm Round Cap, Push-on / Push-Off
612-TL2230-OA | Mouser | SB0030 |  | E-Switch | TL2230OAF140 | Switch, Push Button, DPDT, 5x5mm Rect Cap, Momentary
612-TL2230EEF100 | Mouser | SB0030 |  | E-Switch | TL2230EEF100 | Switch, Push Button, DPDT, 5x5 Rect Cap, Push-on / Push-Off
612-1DFBLK | Mouser | SB0030 |  | E-Switch | 1DFBLK | Cap, Rectangular 5x5 mm, Black
612-1D-BLK | Mouser | SB0030 |  | E-Switch | 1D-BLK | Cap, Rectangular 5x5 mm, Black
612-1D-GR | Mouser | SB0030 |  | E-Switch | 1D-GRY | Cap, Rectangular 5x5 mm, Gray
450-BA600 | Mouser | SB0011 |  | Eagle Knobs & Dials | 450-BA600 | Knob, 16mm dia, 6mm D-shaft, Black body, no indicator
450-BA761 | Mouser | SB0012 |  | Eagle Knobs & Dials | 450-BA761 | Knob, 16mm dia, 6mm D-shaft, Black body, White indicator
450-BA261 | Mouser | SB0012 |  | Eagle Knobs & Dials | 450-BA261 | Knob, 16mm dia, 6mm D-shaft, Black body, Yellow indicator
450-BA161 | Mouser | SB0012 |  | Eagle Knobs & Dials | 450-BA161 | Knob, 16mm dia, 6mm D-shaft, Black body, Red indicator
450-BA361 | Mouser | SB0012 |  | Eagle Knobs & Dials | 450-BA361 | Knob, 16mm dia, 6mm D-shaft, Black body, Blue indicator
450-4760 | Mouser | SB0012 |  | Eagle Knobs & Dials | 450-4760 | Knob, 13.5mm dia, 6mm D-shaft, Black body, White indicator
450-4764 | Mouser | SB0012 |  | Eagle Knobs & Dials | 450-4764 | Knob, 13.5mm dia, 6mm D-shaft, Black body, Green indicator
450-4660 | Mouser | SB0012 |  | Eagle Knobs & Dials | 450-4660 | Knob, 13.5mm dia, 6mm D-shaft, Gray body, Black indicator
450-AE141 | Mouser | SB0031 |  | Eagle Knobs & Dials | 450-AE141 | Knob, 13.7mm dia, 6mm T18-shaft, Black body, White indicator
450-AE185 | Mouser | SB0031 |  | Eagle Knobs & Dials | 450-AE185 | Knob, 18.2mm dia, 6mm T18-shaft, Gray body, Black indicator
450-BA760 | Mouser | SB0031 |  | Eagle Knobs & Dials | 450-BA760 | Knob, 16mm dia, 6mm T18-shaft, Black body, White indicator

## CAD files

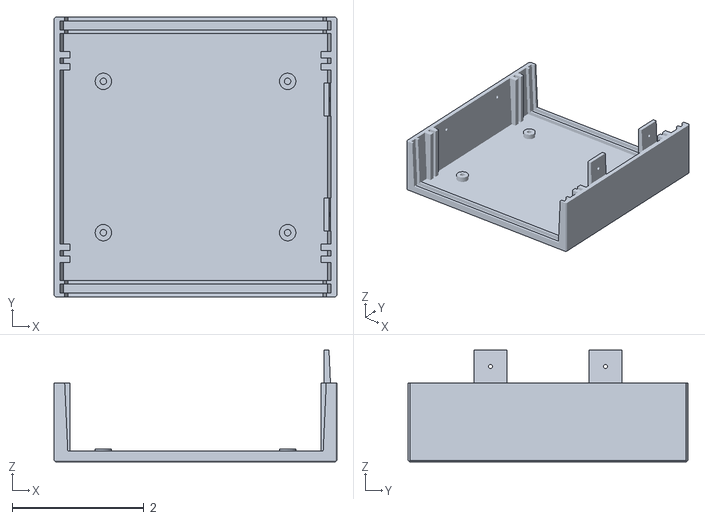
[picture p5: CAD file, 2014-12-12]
Enclosure/Series100halfcaseRev3.1.stl
4.30 x 4.25 x 1.70

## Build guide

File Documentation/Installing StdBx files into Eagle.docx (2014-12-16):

# Installing StdBx Files into Eagle CAD

This is a first and pretty rough draft. Provide feedback by opening issues in GitHub or send email to stdbxmdrtr@gmail.com. These instructions were developed on and for Eagle 6.6.0 running on a Windows 7 PC. If you have a different version of Eagle or a different OS you may need to adapt the instructions to your system.

If you are an experienced Eagle user and experienced with GitHub then here is the short version: Put the repository files from the Eagle Files folder in the right places. The .lbr files go in your Eagle Libraries folder. The .cam file goes in the Eagle cam folder. Optionally, you can also copy the Series100 Examples folder and its contents to your Eagle projects folder.

If the last paragraph is not so clear, read on.

In the Series100 repository (https://github.com/StdBx/Series100) there are two folders of files that need to be added to your Eagle CAD installation. The first step is to download the files from GitHub. And the easiest way to do that is to download the repository as a zip file by clicking on the Download ZIP button on the right-hand side of the repository screen.

The files go into different locations depending on how you set up Eagle on your system. The files can be stored in the Eagle installation folder, but that has some issues. First you have to be an administrator on your system and second the files will have to be moved or copied every time you get an update to Eagle.

A better solution is to create an Eagle folder in a separate place, like MyDocuments, and point Eagle at that. Here (http://www.baldengineer.com/blog/2014/01/03/eagle-create-custom-library/) is a good tutorial on setting up the folders outside of Eagle. You at least need to set up the library folder, the projects folder and the cam folder.

Once you have the folders set up, copy the file StdBxLibrary from the Eagle Files folder inside the zip file to the library folder you created. Copy the file StdBxSeries100 to the cam folder you created. Copy the Series100 Examples folder to the projects folder you created.

NOTE: There are two library files, StdBxLibrary and StdBxLibrary_BETA_. The BETA file contains additional components that have not yet been proven. You can install both if you want. If you use components from StdBxLibrary_BETA_, recognize that you have a greater risk of something not working right. And right now since StdBx is just getting started, virtually all the components are in the BETA library. These will move one-by-one to StdBxLibrary as they are proven.

The next time you open Eagle, the files you copied should show up in the Eagle Control panel in their respective folders. In the Libraries folder there is a dot to the right of the StdBxLibrary file. The dot is likely small and grayish. Click on the dot. It should become larger and green. This is telling Eagle to make this library active in the schematic editor.

Your StdBx additions to Eagle are now installed. You can start your StdBx design by following the instructions in “Designing a Series100 Front Panel”.

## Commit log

2014-12-12 Starting Documentation and initial files
    [PartsDB.xlsx, Series100halfcaseRev3.1.stl]
2014-12-12 Adding Libraries and Proto Boards
    [StdBx Proto Board w UNO(ALPHA).brd, StdBx Proto Board w UNO(ALPHA).sch, StdBx Proto Board(ALPHA).brd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]
2014-12-12 Adding documentation
    [StdBx Proto Board w UNO(ALPHA).brd, StdBx Proto Board w UNO(ALPHA).sch, StdBx Proto Board(ALPHA).brd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]
2014-12-16 Updated descriptions in libraries,...
    sync'd up file name change in README
    [PartsDB.xlsx]
2015-01-08 adding smaller version of Sampler picture
